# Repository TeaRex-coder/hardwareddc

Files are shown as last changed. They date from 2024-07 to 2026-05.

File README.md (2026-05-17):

<h1 align="center">HardwareDDC</h1>
<h4 align="center">A custom PCB that makes adjusting monitor settings easy and convenient</h4>

<!-- Horizontal layout with 3 images -->
<p align="center">
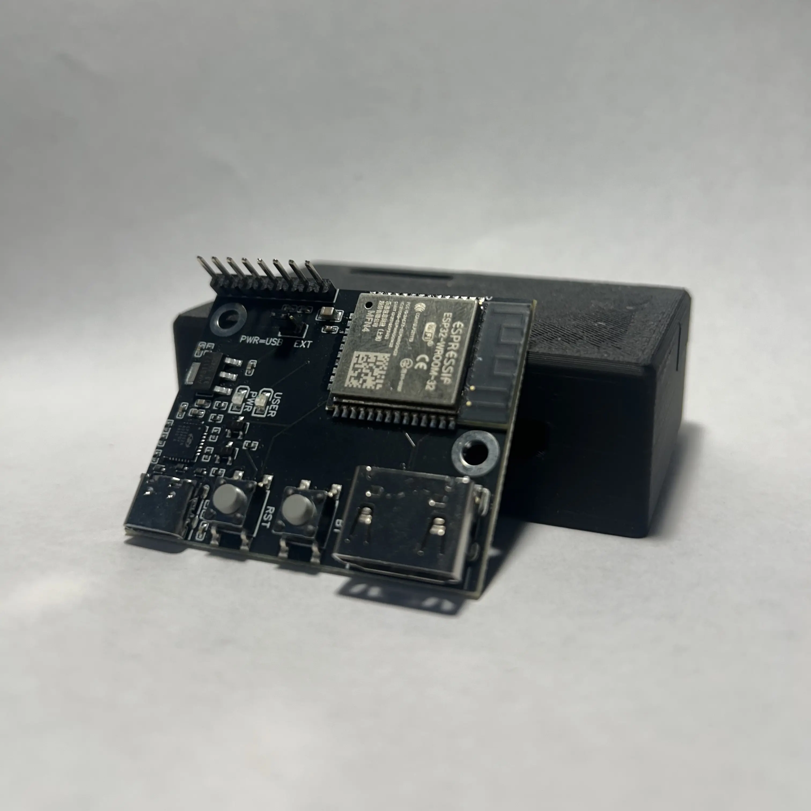
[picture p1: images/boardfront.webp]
front-view
  
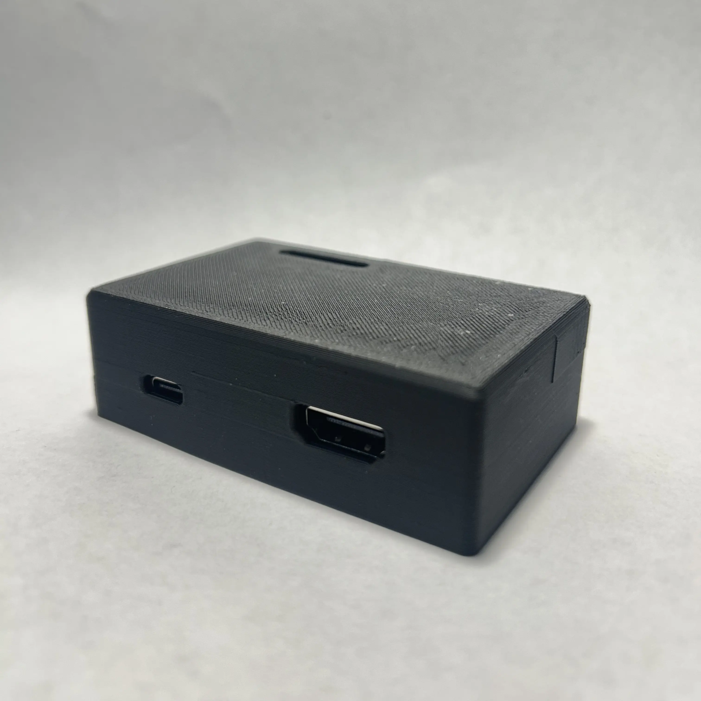
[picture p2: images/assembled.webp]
assembled
  
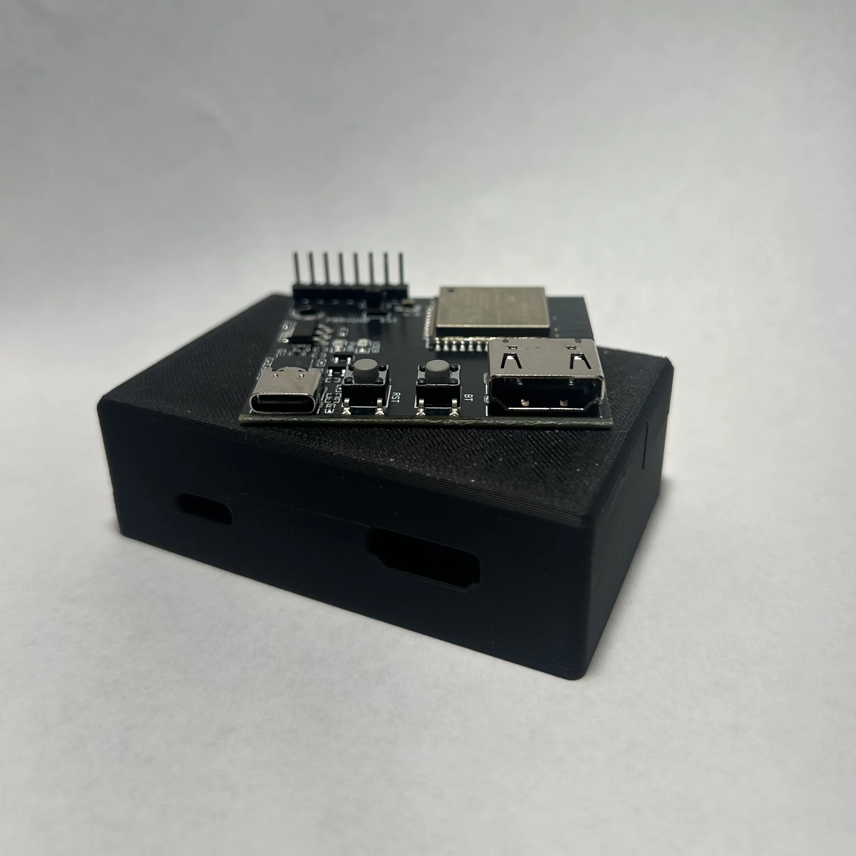
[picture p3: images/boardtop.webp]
top-view
  
</p>

## What is DDC?

DDC/CI (Display Data Channel Command Interface) lets you control monitors with software instead of navigating the nipple or rear buttons. In a perfect world, we could control all monitors with DDC, but unfortunately, that's not the case...

- Some monitors simply don't support DDC :(
- Some monitors like Samsung's G9 ultrawides support DDC only on HDMI
- \*nix (i.e. macOS & Linux) users of DisplayLink don't have DDC support
- Your monitor only supports DDC through HDMI (not DisplayPort)

If you're in one of those last three situations HardwareDDC might be for you! It uses an ESP32 to send raw I<sup>2</sup>C DDC signals to your monitor's HDMI port while another port is used for video.

## Getting Started

HardwareDDC features an ESP32 with reset and boot buttons, an HDMI connector exposing GND, SDA and SCL, and it's powered by USB-C which also exposes the UART console. Optionally, it can be powered by 5V directly through the GPIO pins, and additional GPIO pins are available for debugging and future expandability.

The PCB and the 3D printed ABS case are available on the [website](https://hardwareddc.alexandreboutoille.com), and the files can be found [here](./hardware/README.md).

Once you have your board, you can flash the firmware with the [web installer](https://hardwareddc.alexandreboutoille.com).

Controlling HardwareDDC is done through hotkeys, instructions can be found [here](./ui/README.md)

---

## Sponsors

PCBWay Logo

Thank you PCBWay for sponsoring this project providing PCB prototyping <3

<details>
<summary>Review & Opinions</summary>

TL;DR Would I recommend PCBWay's PCB service? Yes!

It's impossible for me to provide an unbiased opinion as PCBWay has provided boards free of charge to help me work on this project. However, my experience was overall positive. Starting with their marketing rep Liam, he offered a partnership respectfully and fairly. When placing the order, the team helped me, a novice to PCB design and PCBWay's services, follow some best practices regarding board design and ordering. Finally, the production tracker helped keep my curious mind informed and the assembled product functioned as intended.

When researching PCBWay's brand before agreeing to a partnership, I noticed a customer expressing disappointment in the assembly of an HDMI connector. I took this with a grain of salt, as the dissatisfied customers are generally the loudest, but it was still a concern. The boards I received had well-soldered DisplayPort connector pins to a level as good, if not better than I could do by hand.

<p align="center">
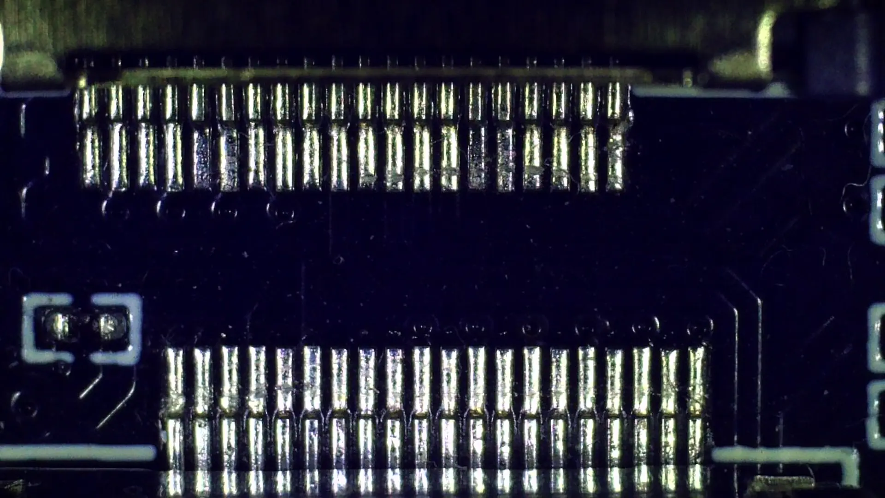
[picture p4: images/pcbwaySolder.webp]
PCBWay Logo
  
</p>

I hope the experience I received is representative of any regular PCBWay customer despite PCBWay expecting a review. If you need PCB prototyping for your project, consider giving them a go :)

</details>

Flux Logo

Thank you Flux AI for providing [breakout boards](./experiments/hardwareddc-aux-breakout) for HardwareDDC <3

## Future Ideas

- [x] Improve Microsoft Windows UX/Create Proper User Interface
  - [ ] Add more information to GUI (e.g. connection status)
  - [ ] Enable user-modifiable hotkeys
- [ ] Support Multiple Monitors
- [ ] Create a non-network-based approach

## Extras

Shoutout to these projects that make HardwareDDC possible:

- [ESP Web Tools](https://github.com/esphome/esp-web-tools)
- [Improv Wi-Fi](https://github.com/jnthas/Improv-WiFi-Library)
- [DDC/CI VCP library](https://github.com/tttttx2/ddcvcp)

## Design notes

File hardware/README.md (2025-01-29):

# Hardware

HardwareDDC comes with an optional two-part 3D-printed case which you can re-print yourself.

## BOM:

| Quantity | Description |
| --- | --- |
| 4 | M3x4x5 Heat set insert (the "Voron ones") |
| 2 | M3x6 BHCS |
| 4 | M3x6 FHCS |
| 1 | [Printed parts](./case/) |

## Print settings:

_it doesn't matter that much, but it's what I used_

- Layer height: 0.2mm
- Extrusion width: 0.4mm
- Infill: 20%
- Walls: 4
- Top/bottom layers: 5
- No supports
- Material: Board gets warm so I used ABS, but PLA should work

## Assembly:

### Step 1: Add Heatset Inserts

- 4 x Heat Set Insert

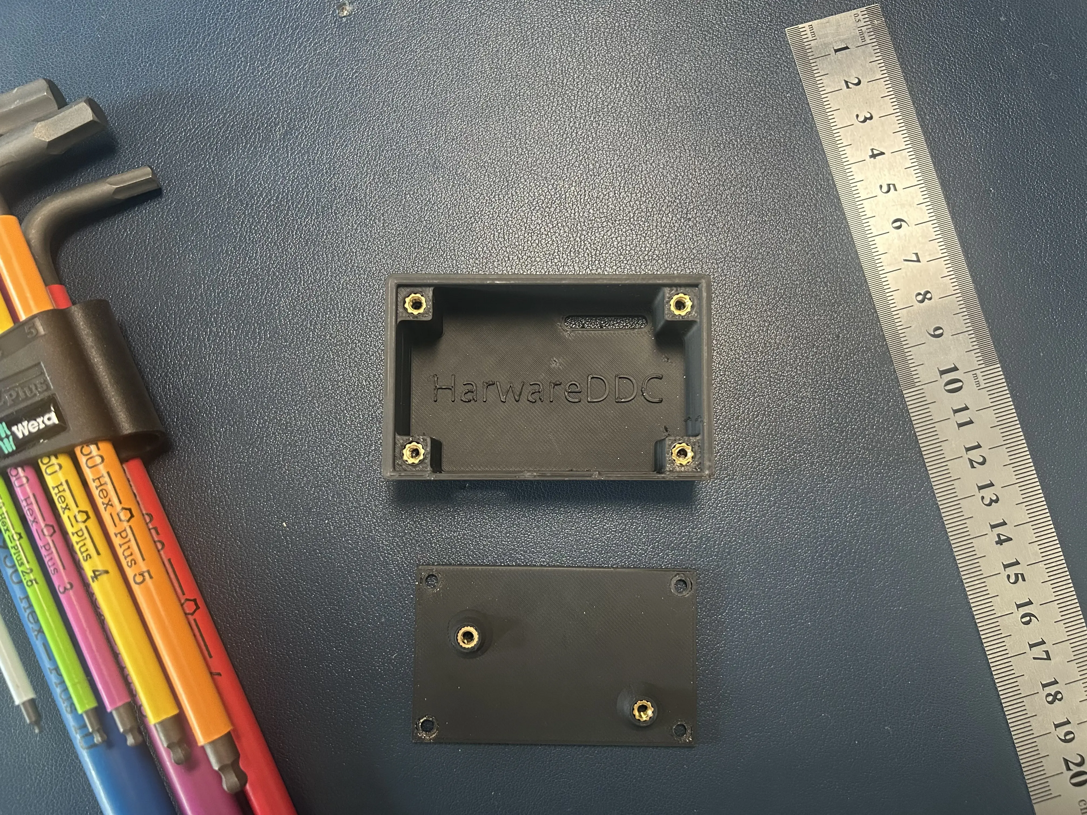
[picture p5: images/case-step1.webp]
case step 1


<br>

### Step 2: Place PCB

- 2 x M3x6 BHCS

_Make sure fasteners are centered in the board holes (future revision will reduce the tolerance)_

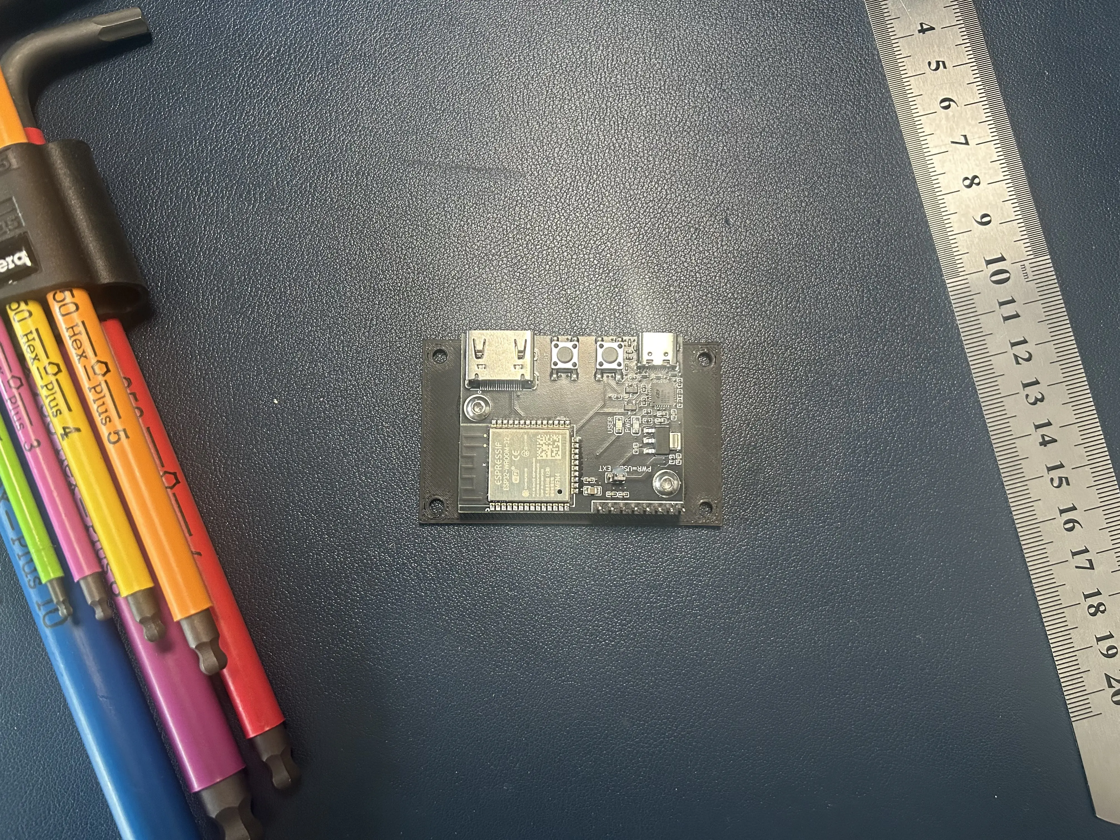
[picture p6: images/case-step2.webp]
case step 2


<br>

### Step 3: Close Case

- 4 x M3x6 FHCS

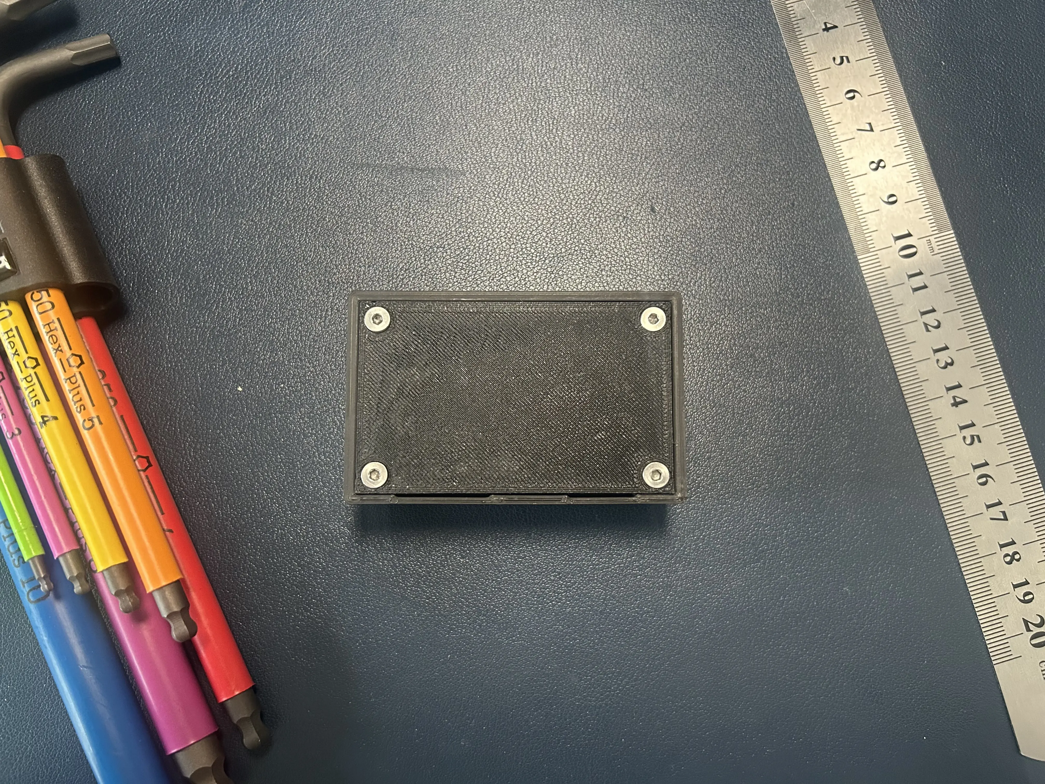
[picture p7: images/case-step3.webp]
case step 3


<br>

_The PCB is not yet fully open-source, however the schematic can be found [here](./pcb/HardwareDDC_rev1.0_schematic.pdf.pdf)_

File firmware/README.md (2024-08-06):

# Firmware

## Building

HardwareDDC is built using Espressif's ESP32-WROOM-32E-N4.

Build environment tools:

- [esptool.py](https://github.com/espressif/esptool)
- [PlatformIO](https://github.com/platformio)

### Generate image

```bash
esptool.py --chip esp32 merge_bin -o image.bin --flash_mode dio --flash_size 4MB 0x1000 .pio/build/esp32dev/bootloader.bin 0x8000 .pio/build/esp32dev/partitions.bin 0x10000 .pio/build/esp32dev/firmware.bin
```

### Flash Image

```bash
esptool.py --chip esp32 --port <serial port> write_flash 0x0 image.bin
```

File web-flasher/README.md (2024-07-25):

# Web Installer

HardwareDDC's web installer uses [ESP Web Tools](https://github.com/esphome/esp-web-tools) to connects to the ESP32's UART console with [esptool-js](https://github.com/espressif/esptool-js) and uses [Improv](https://github.com/improv-wifi) to configure Wi-Fi over serial.

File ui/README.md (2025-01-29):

# User Interface

HardwareDDC's goal is to provide and easy and convenient way to adjust monitor settings. Currently, HardwareDDC is controlled through an efficient macro-based UI.

## macOS

Lunar, _the defacto app for controlling monitors_, is used as HardwareDDC's macOS GUI.

1. Install [Lunar](https://static.lunar.fyi/releases/Lunar.dmg)
2. Disable all controls aside from _Network (Raspberry Pi)_
3. Reset _Network Control_

## Windows

1. Install [hardwareddc-amd64-installer.exe](https://github.com/TeaRex-coder/hardwareddc/releases) from the latest GitHub release

### Hotkeys

_User-modifiable hotkeys to come_

**Brightness:**

- ⌥⇧- = +10%
- ⌥⇧= = +10%

- ⌥⇧1 = 25%
- ⌥⇧2 = 50%
- ⌥⇧3 = 75%
- ⌥⇧4 = 100%
- ⌥⇧5 = 0%

**Input Source:**

- ⌥⇧d1 = DisplayPort 1
- ⌥⇧d2 = DisplayPort 2
- ⌥⇧h1 = HDMI 1
- ⌥⇧h2 = HDMI 2

## Linux

_Sorry, GNU/Linux_

This is coming soon, but you're a Linux user, you can figure it out.

**Example API calls to get you started:**

Specify brightness percentage:

```bash
curl -X GET "http://ddcutil.local:3485/1/brightness/<value 0-100>"
```

Get current brightness:

```bash
curl -X GET "http://ddcutil.local:3485/1/brightness"
```

Change input source:

```bash
curl -X GET "http://ddcutil.local:3485/1/input_source/<hexadecimal source>"
```

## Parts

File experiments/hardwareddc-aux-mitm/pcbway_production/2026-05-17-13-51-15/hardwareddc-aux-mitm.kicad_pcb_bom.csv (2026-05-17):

Designator | Quantity | Value | Footprint | Package | MPN | DNP | Mount_Type | Description | KiLib_Generator | MF | MP | Description_1 | Price
C1, C3, C4, C5, C8, C9 | 6 | 100n | C_0402_1005Metric |  |  |  | smt | Unpolarized capacitor | SMD_2terminal_chip_molded
C10, C7 | 2 | 10uF | C_0603_1608Metric |  |  |  | smt | Unpolarized capacitor | SMD_2terminal_chip_molded
C11 | 1 | 100nF | C_0603_1608Metric |  |  |  | smt | Unpolarized capacitor | SMD_2terminal_chip_molded
C2, C6 | 2 | 1n | C_0402_1005Metric |  |  |  | smt | Unpolarized capacitor | SMD_2terminal_chip_molded
D1 | 1 | D_TVS | D_SOD-323 |  |  |  | smt | Bidirectional transient-voltage-suppression diode
J1, J4 | 2 | 47272-0001 | CONN_47272-0001_MOL |  |  |  | smt |  |  | Molex | 472720001
J5 | 1 | HDMI_A | HDMI_A_Molex_208658-1001_Horizontal |  |  |  | smt | HDMI type A connector
J6 | 1 | USB_C_Receptacle_USB2.0_16P | USB_C_Receptacle_GCT_USB4105-xx-A_16P_TopMnt_Horizontal |  |  |  | smt | USB 2.0-only 16P Type-C Receptacle connector
J7 | 1 | Conn_02x02_Odd_Even | PinHeader_2x02_P2.54mm_Vertical |  |  |  | tht | Generic connector, double row, 02x02, odd/even pin numbering scheme (row 1 odd numbers, row 2 even numbers), script generated (kicad-library-utils/schlib/autogen/connector/) | connector/pin_header_socket
J8 | 1 | Conn_02x04_Odd_Even | PinHeader_2x04_P2.54mm_Vertical |  |  |  | tht | Generic connector, double row, 02x04, odd/even pin numbering scheme (row 1 odd numbers, row 2 even numbers), script generated (kicad-library-utils/schlib/autogen/connector/) | connector/pin_header_socket
R1, R8 | 2 | 10k | R_0402_1005Metric |  |  |  | smt | Resistor | SMD_2terminal_chip_molded
R10, R3 | 2 | 1K5 | R_0402_1005Metric |  |  |  | smt | Resistor | SMD_2terminal_chip_molded
R11, R12, R4, R5 | 4 | 51 | R_0402_1005Metric |  |  |  | smt | Resistor | SMD_2terminal_chip_molded
R13, R14 | 2 | 1M | R_0402_1005Metric |  |  |  | smt | Resistor | SMD_2terminal_chip_molded
R15, R16, R17, R18, R19, R20 | 6 | 0 | R_0603_1608Metric |  |  |  | smt | Resistor | SMD_2terminal_chip_molded
R2, R9 | 2 | 3K3 | R_0402_1005Metric |  |  |  | smt | Resistor | SMD_2terminal_chip_molded
R21, R22 | 2 | 5K1 | R_0402_1005Metric |  |  |  | smt | Resistor | SMD_2terminal_chip_molded
R6, R7 | 2 | 100K | R_0402_1005Metric |  |  |  | smt | Resistor | SMD_2terminal_chip_molded
U1, U2 | 2 | SN65MLVD200AD | SOIC-8_3.9x4.9mm_P1.27mm | SOIC-8 Texas Instruments |  |  | smt |  | package/gullwing | Texas Instruments | SN65MLVD200AD | Half-duplex M-LVDS transceiver | None
U3 | 1 | AMS1117-3.3 | SOT-223-3_TabPin2 |  |  |  | smt | 1A Low Dropout regulator, positive, 3.3V fixed output, SOT-223

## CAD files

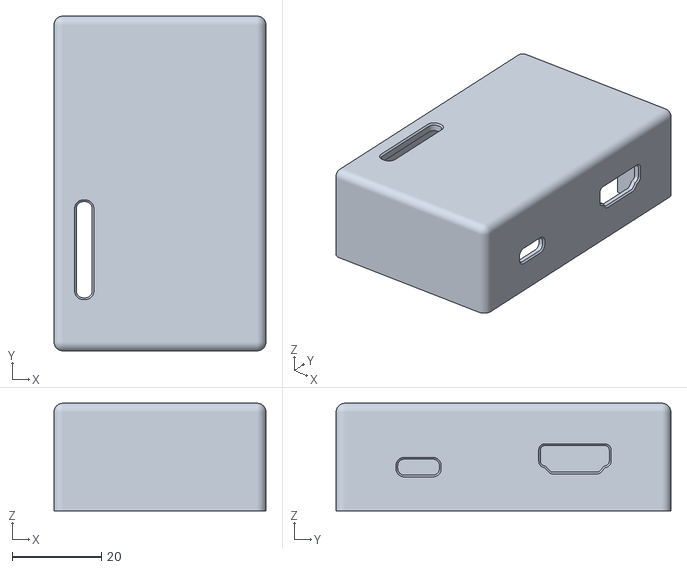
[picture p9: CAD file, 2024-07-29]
hardware/case/HardwareDDC-case-top.stl
47.5 x 75.0 x 24.1

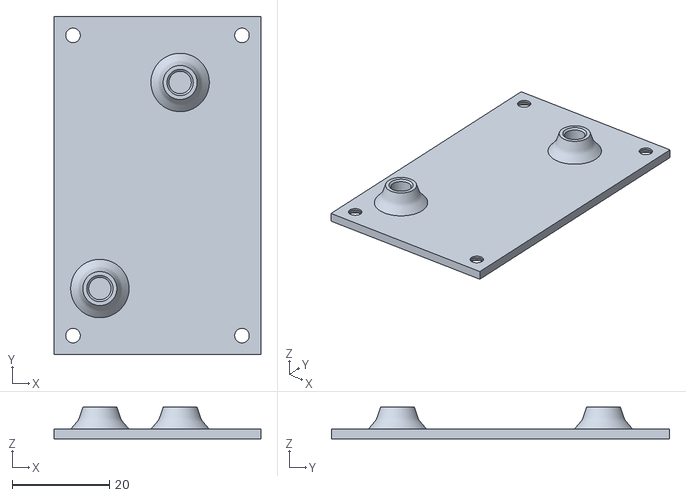
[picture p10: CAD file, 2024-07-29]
hardware/case/HardwareDDC-case-bottom.stl
42.5 x 69.5 x 6.50

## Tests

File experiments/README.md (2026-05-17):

# HardwareDDC Experiments

_I do a lot of work behind the scene to learn about DDC-related tech. In this directory, I want to share some of my fun HardwareDDC experiments._

## HardwareDDC Aux V1.0

This board uses the [PTN3392](https://www.nxp.com/docs/en/data-sheet/PTN3392.pdf) DisplayPort to VGA IC to convert DP Aux into i2c

Goals:

- Reduce latency
- No client software

[Schematic](./hardwareddc-aux-v1.0/hardwareddc-aux-v1.0.pdf)

[ECAD files](./hardwareddc-aux-v1.0/hardwareddc-aux-v1.0.zip)

Learnings:

- This solution is jank and pretty unstable
- Next time, I'll try using [TI's M-LVDS](https://www.ti.com/lit/ug/tidu599/tidu599.pdf) transceivers to interact with the Aux channel

## HardwareDDC Aux 2.0 "Breakout"

This board _attempts_ to "sniff" the DisplayPort auxiliary channel using [TI's SN65MLVD200AD](https://www.ti.com/lit/ds/symlink/sn65mlvd200a.pdf).

What I learned:

- How to better route high-speed differential pairs (DisplayPort video signal)
- Improved understanding of DisplayPort AUX

What didn't work:

- Sniffing the AUX channel

I think it didn't work because of my false assumptions of the physical hardware layout of DisplayPort AUX on both the source and sink. Possible also because of the assumptions I made before understanding the communication protocol.

In the future, I'll be trying using a more traditional Hardware layout as suggested in the DisplayPort 1.2 standards document to using a more MitM-like approach inspired by [JX5S' work](https://github.com/JX5S/DP_aux_emulator).

## HardwareDDC AUX 2.1 "MitM"

WIP

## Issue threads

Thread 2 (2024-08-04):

Incorrect values for input sources for Odyssey G9 OLED

dlpullen, 2024-08-04:
Currently, the code limits the "valid" input source values to 4 values in the handleSetSource function in http.cpp.

These values are:
- 0x0f
- 0x10
- 0x11
- 0x12

The Odyssey G9 OLED is apparently a little different. It only has 3 inputs and the values are:
- 0x05 (Full-size HDMI aka HDMI 1)
- 0x06 (Mini HDMI aka HDMI 2)
- 0x0f (Display Port)

I would propose to either remove the check in line 108 in http.cpp or to add these values to the checked items. I am unsure how much variety there is across different monitors that might benefit from hardwareddc.

As a quick point of comparison, I have some Dell 2721QS monitors with fantastic ddc support. So, no need for hardwareddc for them. But, There input values are:
- 0x0f (Display Port)
- 0x11 (HDMI 1)
- 0x12 (HDMI 2)

These are in better alignment (a subset) with the values you already have setup in the if statement.

TeaRex-coder, 2024-08-06:
Thanks for opening your issue! I've re-written the API endpoints and removed the check in `http.cpp`.

To switch to HDMI 1 you can now send a request to `http://ddcutil.local:3485/1/input_source/0x05`, more info in the [documentation](/TeaRex-coder/hardwareddc/tree/main/ui).

I'll merge the `api-v2` branch with a PR and close this issue.

Closed 2024-08-06.

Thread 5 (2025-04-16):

ESP32 with HDMI port

denisgabriel5, 2025-04-16:
My question is where can I purchase and ESP32 with an HDMI port.

I did a quick Google search and I couldn't find such a device.

If it is possible, I would appreciate a link to such a device that is available to purchase from within the European Union.

TeaRex-coder, 2025-06-28:
Answered on [Reddit](https://old.reddit.com/r/ultrawidemasterrace/comments/1dxoh3b/comment/mne3k59/)

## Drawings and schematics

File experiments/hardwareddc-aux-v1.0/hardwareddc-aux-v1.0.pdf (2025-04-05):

# HardwareDDC Aux

DP INPUT | DP OUTPUT | HDMI OUTPUT

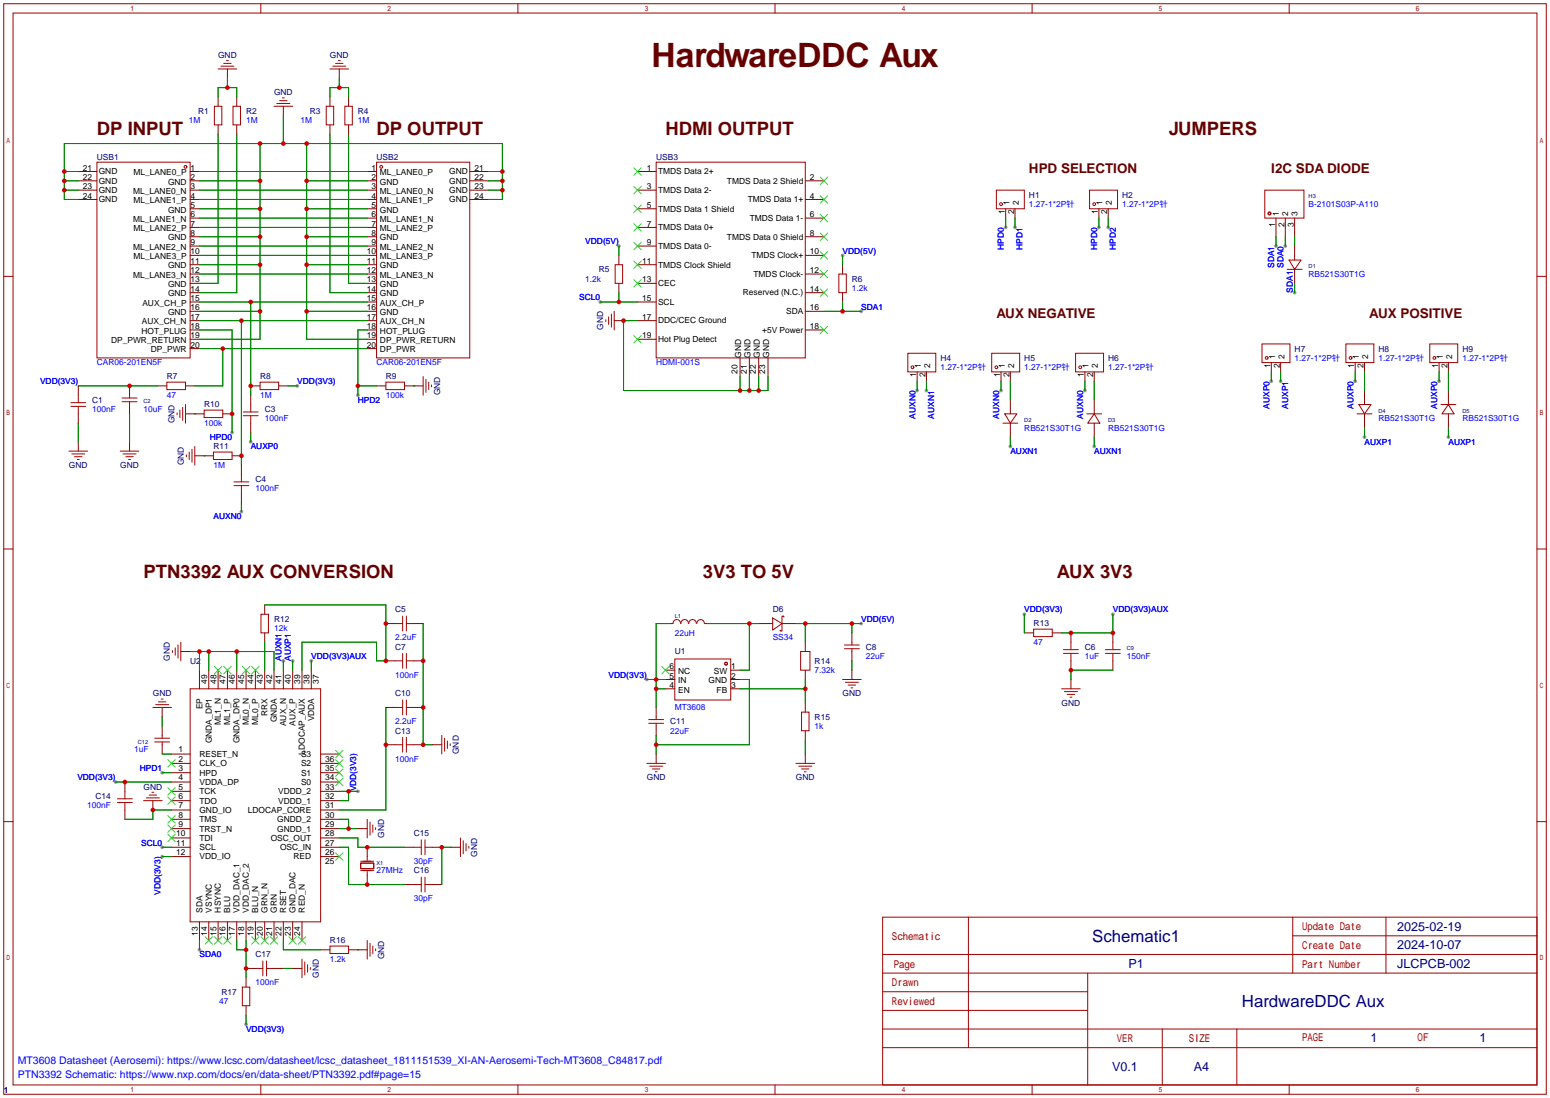
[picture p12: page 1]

EP 49 GNDA_DP1 48 ML1_N 47 ML1_P 46 GNDA_DP0 45 ML0_N 44 ML0_P 43 RRX 42 GNDA 41 AUX_N 40 AUX_P 39 LDOCAP_AUX 38 VDDA 37

MT3608 Datasheet (Aerosemi): https://www.lcsc.com/datasheet/lcsc_datasheet_1811151539_XI-AN-Aerosemi-Tech-MT3608_C84817.pdf
PTN3392 Schematic: https://www.nxp.com/docs/en/data-sheet/PTN3392.pdf#page=15

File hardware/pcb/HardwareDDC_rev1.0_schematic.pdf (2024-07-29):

# HardwareDDC

POWER INPUT SELECTION | 5V TO 3.3V | POWER LED | USER LED

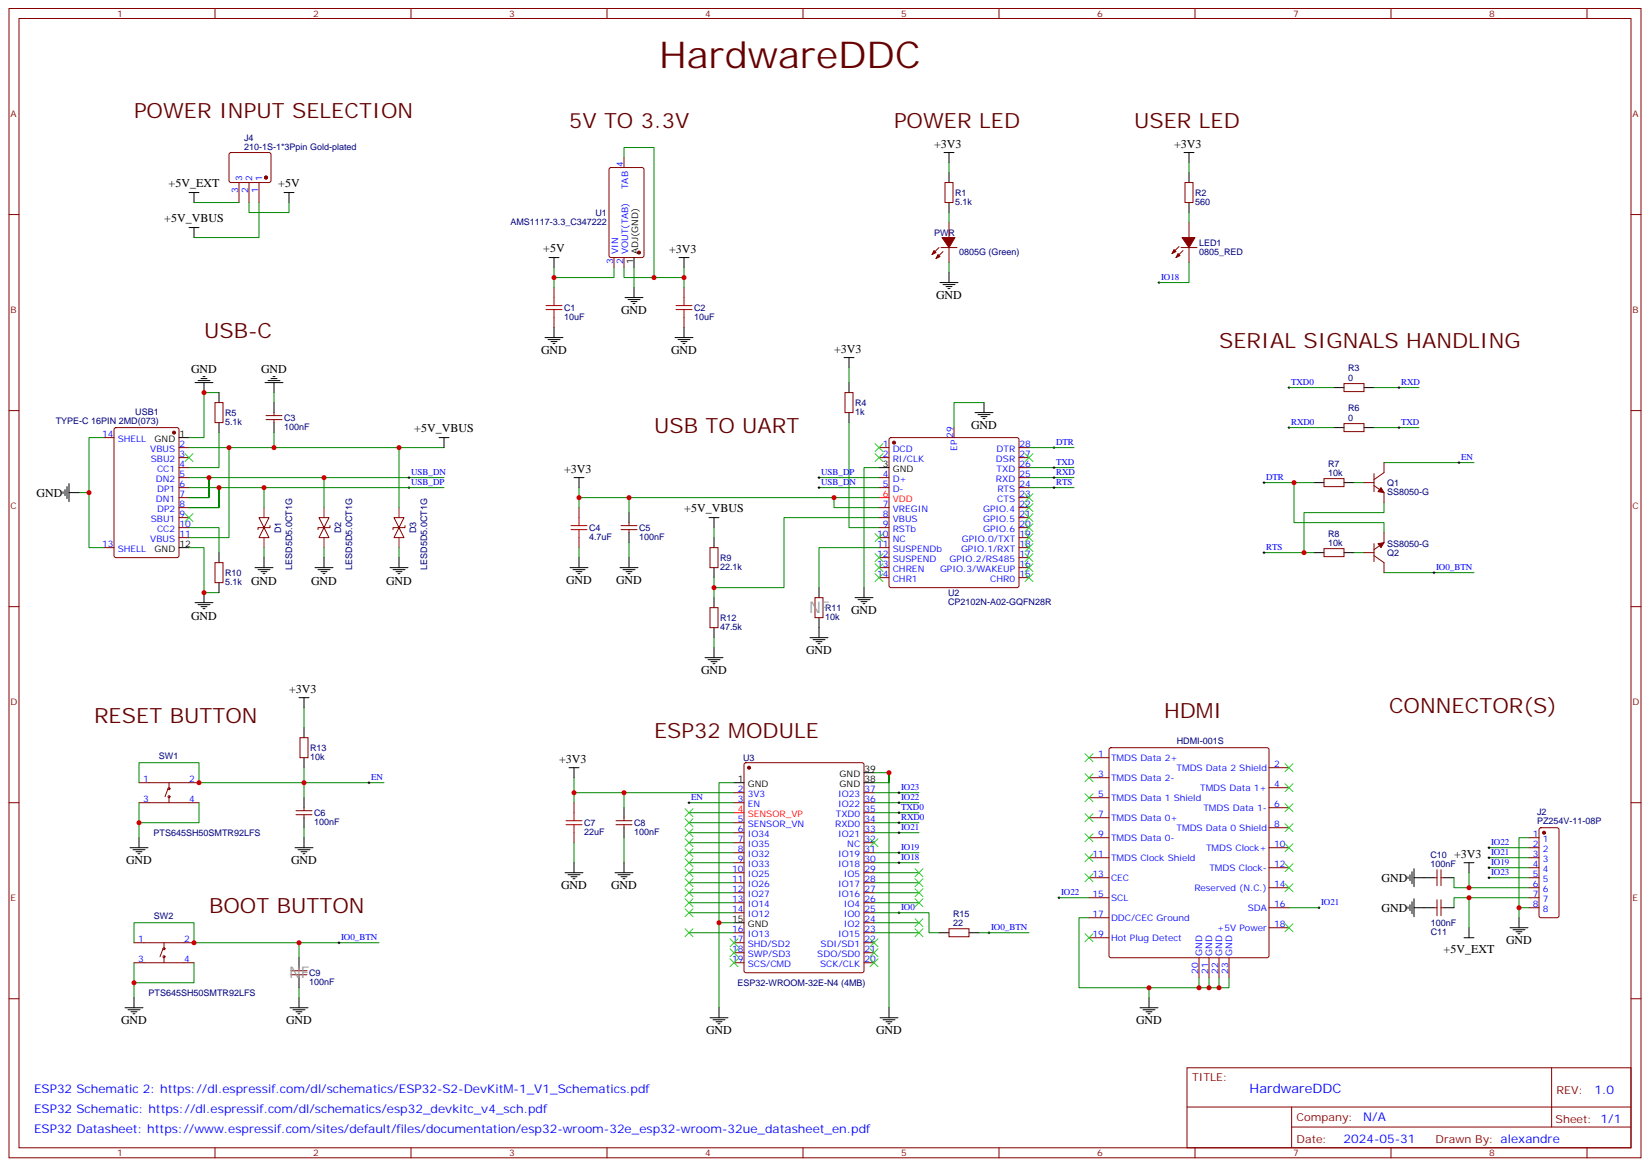
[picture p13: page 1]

ESP32 Schematic 2: https://dl.espressif.com/dl/schematics/ESP32-S2-DevKitM-1_V1_Schematics.pdf
ESP32 Schematic: https://dl.espressif.com/dl/schematics/esp32_devkitc_v4_sch.pdf
ESP32 Datasheet: https://www.espressif.com/sites/default/files/documentation/esp32-wroom-32e_esp32-wroom-32ue_datasheet_en.pdf

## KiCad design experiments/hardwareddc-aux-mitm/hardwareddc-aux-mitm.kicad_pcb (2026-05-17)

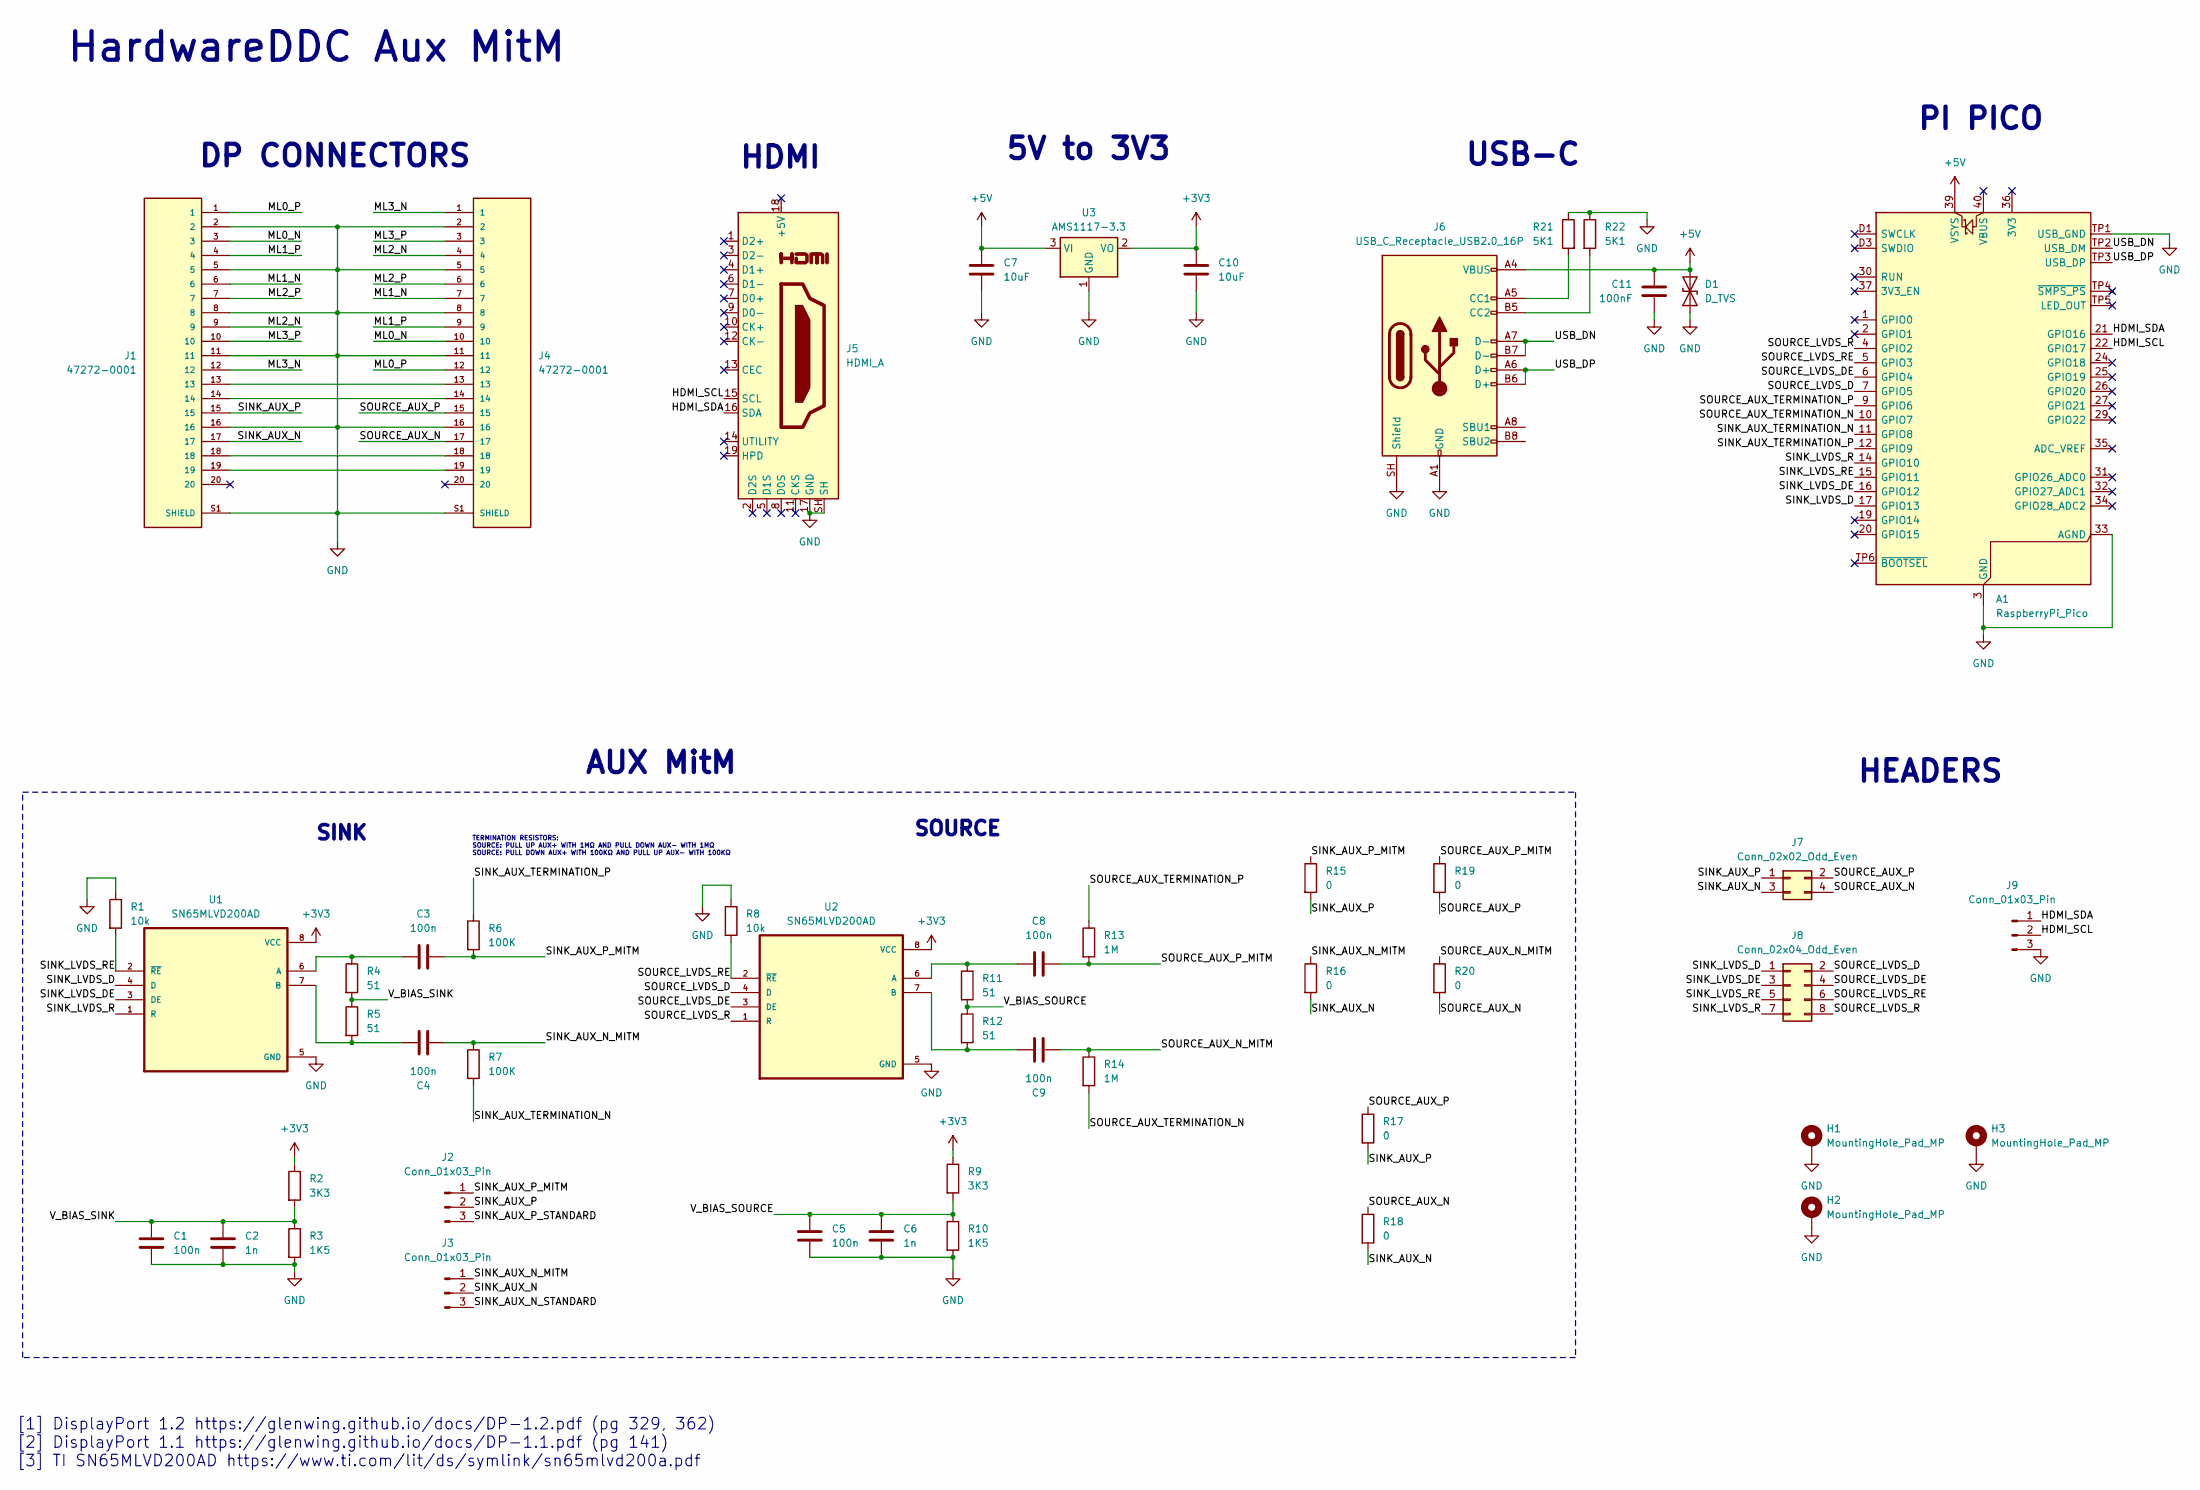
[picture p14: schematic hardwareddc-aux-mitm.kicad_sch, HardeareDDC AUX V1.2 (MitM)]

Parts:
A1: RaspberryPi_Pico; RaspberryPi_Pico_SMD
C1, C3, C4, C5, C8, C9: 100n; C_0402_1005Metric
C2, C6: 1n; C_0402_1005Metric
C7, C10: 10uF; C_0603_1608Metric
C11: 100nF; C_0603_1608Metric
D1: D_TVS; D_SOD-323
H1, H2, H3: MountingHole_Pad_MP; MountingHole_2.2mm_M2_ISO7380_Pad
J1, J4: 47272-0001; CONN_47272-0001_MOL
J2, J3: Conn_01x03_Pin
J5: HDMI_A; HDMI_A_Molex_208658-1001_Horizontal
J6: USB_C_Receptacle_USB2.0_16P; USB_C_Receptacle_GCT_USB4105-xx-A_16P_TopMnt_Horizontal
J7: Conn_02x02_Odd_Even; PinHeader_2x02_P2.54mm_Vertical
J8: Conn_02x04_Odd_Even; PinHeader_2x04_P2.54mm_Vertical
J9: Conn_01x03_Pin; PinHeader_1x03_P2.54mm_Vertical
R1, R8: 10k; R_0402_1005Metric
R2, R9: 3K3; R_0402_1005Metric
R3, R10: 1K5; R_0402_1005Metric
R4, R5, R11, R12: 51; R_0402_1005Metric
R6, R7: 100K; R_0402_1005Metric
R13, R14: 1M; R_0402_1005Metric
R15, R16, R17, R18, R19, R20: 0; R_0603_1608Metric
R21, R22: 5K1; R_0402_1005Metric
U1, U2: SN65MLVD200AD; SOIC-8_3.9x4.9mm_P1.27mm
U3: AMS1117-3.3; SOT-223-3_TabPin2

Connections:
+3V3: C10.1, R2.1, R9.1, U1.8 (VCC), U2.8 (VCC), U3.2 (VO)
+5V: A1.39 (VSYS), C7.1, C11.1, D1.2 (A2), J6.A4 (VBUS), J6.A9 (VBUS), J6.B4 (VBUS), J6.B9 (VBUS), U3.3 (VI)
/HDMI_SCL: A1.22 (GPIO17), J5.15 (SCL), J9.2
/HDMI_SDA: A1.21 (GPIO16), J5.16 (SDA), J9.1
/ML0_N: J1.3, J4.10
/ML0_P: J1.1, J4.12
/ML1_N: J1.6, J4.7
/ML1_P: J1.4, J4.9
/ML2_N: J1.9, J4.4
/ML2_P: J1.7, J4.6
/ML3_N: J1.12, J4.1
/ML3_P: J1.10, J4.3
/SINK_AUX_N: J1.17, J3.2, J7.3, R16.2, R18.2
/SINK_AUX_N_MITM: C4.2, J3.1, R7.1, R16.1
/SINK_AUX_P: J1.15, J2.2, J7.1, R15.2, R17.2
/SINK_AUX_P_MITM: C3.2, J2.1, R6.2, R15.1
/SINK_AUX_TERMINATION_N: A1.11 (GPIO8), R7.2
/SINK_AUX_TERMINATION_P: A1.12 (GPIO9), R6.1
/SINK_LVDS_D: A1.17 (GPIO13), J8.1, U1.4 (D)
/SINK_LVDS_DE: A1.16 (GPIO12), J8.3, U1.3 (DE)
/SINK_LVDS_R: A1.14 (GPIO10), J8.7, U1.1 (R)
/SINK_LVDS_RE: A1.15 (GPIO11), J8.5, R1.2, U1.2 (~RE)
/SOURCE_AUX_N: J4.17, J7.4, R18.1, R20.2
/SOURCE_AUX_N_MITM: C9.2, R14.1, R20.1
/SOURCE_AUX_P: J4.15, J7.2, R17.1, R19.2
/SOURCE_AUX_P_MITM: C8.2, R13.2, R19.1
/SOURCE_AUX_TERMINATION_N: A1.10 (GPIO7), R14.2
/SOURCE_AUX_TERMINATION_P: A1.9 (GPIO6), R13.1
/SOURCE_LVDS_D: A1.7 (GPIO5), J8.2, U2.4 (D)
/SOURCE_LVDS_DE: A1.6 (GPIO4), J8.4, U2.3 (DE)
/SOURCE_LVDS_R: A1.4 (GPIO2), J8.8, U2.1 (R)
/SOURCE_LVDS_RE: A1.5 (GPIO3), J8.6, R8.2, U2.2 (~RE)
/USB_DN: A1.TP2 (USB_DM), J6.A7 (D-), J6.B7 (D-)
/USB_DP: A1.TP3 (USB_DP), J6.A6 (D+), J6.B6 (D+)
/V_BIAS_SINK: C1.1, C2.1, R2.2, R3.1, R4.2, R5.1
/V_BIAS_SOURCE: C5.1, C6.1, R9.2, R10.1, R11.2, R12.1
GND: A1.3 (GND), A1.8 (GND), A1.13 (GND), A1.18 (GND), A1.23 (GND), A1.28 (GND), A1.33 (AGND), A1.38 (GND), A1.D2 (GND), A1.TP1 (USB_GND), C1.2, C2.2, C5.2, C6.2, C7.2, C10.2, C11.2, D1.1 (A1), H1.1 (MP_1), H2.1 (MP_1), H3.1 (MP_1), J1.2, J1.5, J1.8, J1.11, J1.16, J1.S1 (SHIELD), J1.S2 (SHIELD), J1.S3 (SHIELD), J1.S4 (SHIELD), J4.2, J4.5, J4.8, J4.11, J4.16, J4.S1 (SHIELD), J4.S2 (SHIELD), J4.S3 (SHIELD), J4.S4 (SHIELD), J5.17 (GND), J5.SH, J6.A1 (GND), J6.A12 (GND), J6.B1 (GND), J6.B12 (GND), J6.SH (Shield), J9.3, R1.1, R3.2, R8.1, R10.2, R21.1, R22.1, U1.5 (GND), U2.5 (GND), U3.1 (GND)
unnamed: J1.13, J4.13
unnamed: J1.14, J4.14
unnamed: J1.18, J4.18
unnamed: J1.19, J4.19
unnamed: J6.A5 (CC1), R21.2
unnamed: J6.B5 (CC2), R22.2
unnamed: C3.1, R4.1, U1.6 (A)
unnamed: C4.1, R5.2, U1.7 (B)
unnamed: C8.1, R11.1, U2.6 (A)
unnamed: C9.1, R12.2, U2.7 (B)

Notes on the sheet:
SOURCE
DP CONNECTORS
HardwareDDC Aux MitM
[1] DisplayPort 1.2 https://glenwing.github.io/docs/DP-1.2.pdf (pg 329, 362) [2] DisplayPort 1.1 https://glenwing.github.io/docs/DP-1.1.pdf (pg 141) [3] TI SN65MLVD200AD https://www.ti.com/lit/ds/symlink/sn65mlvd200a.pdf
HEADERS
AUX MitM
5V to 3V3
USB-C
PI PICO
SINK
TERMINATION RESISTORS: SOURCE: PULL UP AUX+ WITH 1MΩ AND PULL DOWN AUX- WITH 1MΩ SOURCE: PULL DOWN AUX+ WITH 100KΩ AND PULL UP AUX- WITH 100KΩ
HDMI

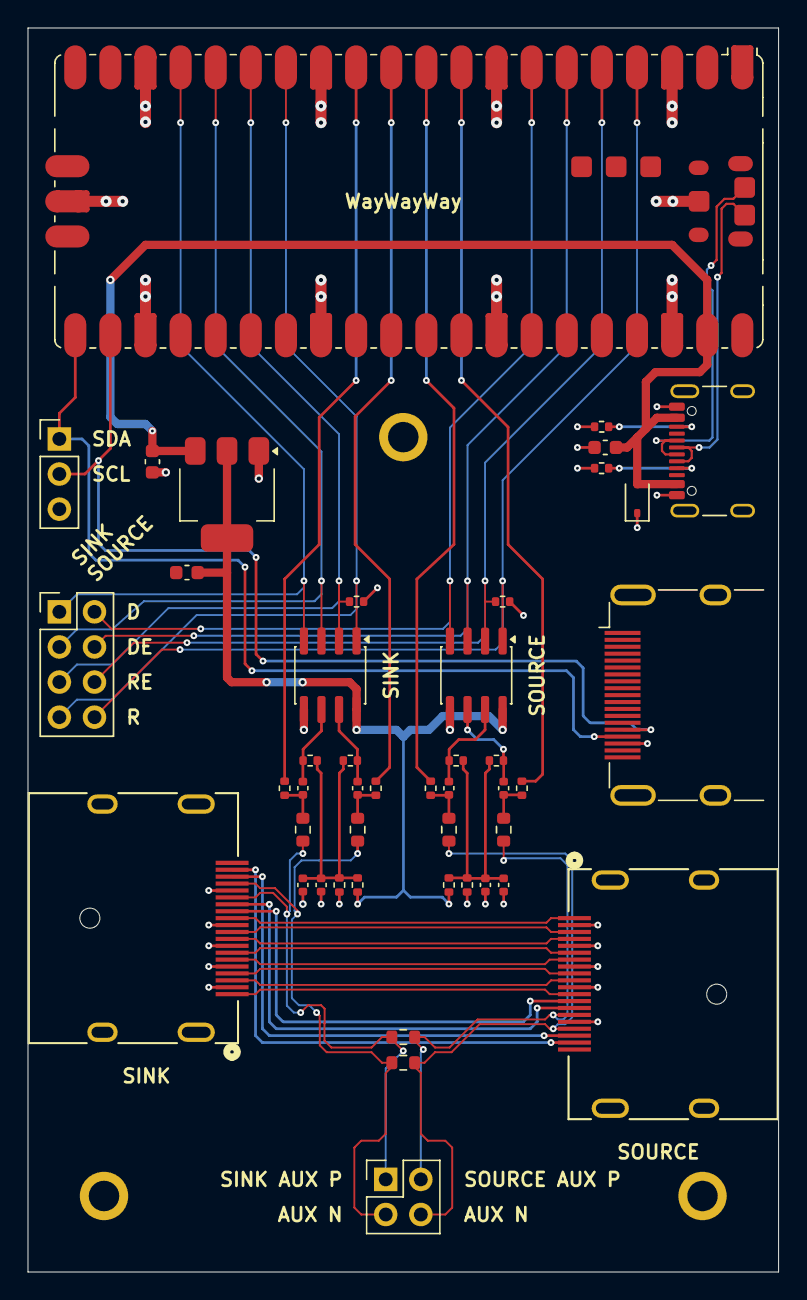
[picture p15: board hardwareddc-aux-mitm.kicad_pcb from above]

Board: 4 copper layers, 54.3 x 90.0 mm, 48 parts (0 on the bottom side), 47 nets.

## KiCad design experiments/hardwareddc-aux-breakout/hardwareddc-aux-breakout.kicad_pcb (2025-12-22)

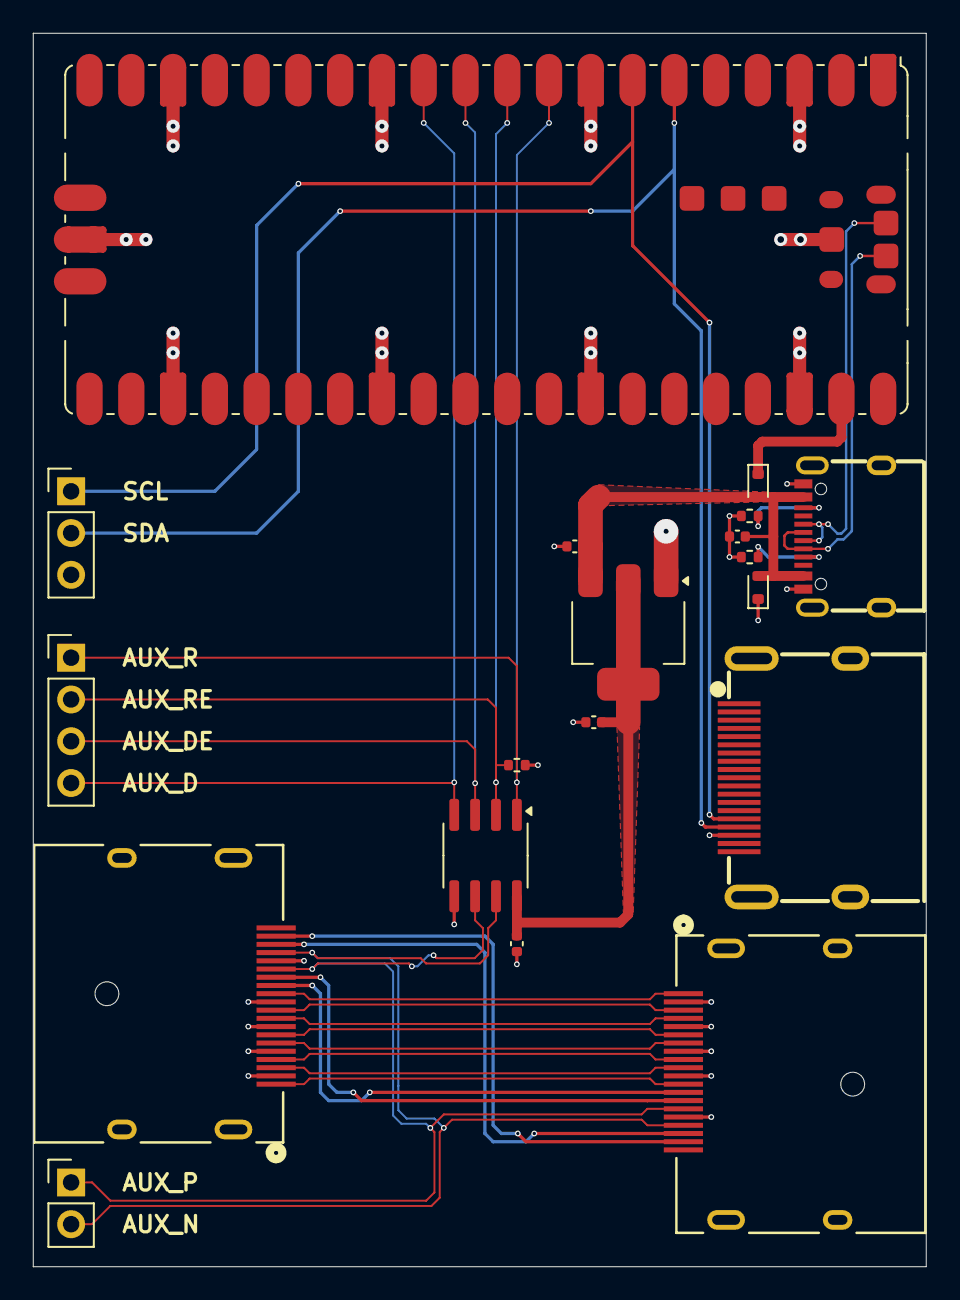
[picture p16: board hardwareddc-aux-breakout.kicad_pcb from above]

Board: 4 copper layers, 54.3 x 75.0 mm, 19 parts (0 on the bottom side), 28 nets.

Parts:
A1: RaspberryPi_Pico; RaspberryPi_Pico_SMD
C1, C2: 100nF; C_0402_1005Metric
C3, C4: 10uF; C_0402_1005Metric
D1: D_TVS; D_SOD-523
D2: D_Schottky; D_SOD-523
J1: Conn_01x04_Pin; PinHeader_1x04_P2.54mm_Vertical
J2: USB_C_Receptacle; USB-C-SMD_TYPE-C-6PIN-2MD-073
J3: Conn_01x03_Pin; PinHeader_1x03_P2.54mm_Vertical
J4: Conn_01x02_Pin; PinHeader_1x02_P2.54mm_Vertical
J5, J6: 472720001; CONN_47272-0001_MOL
J7: HDMI_A_1.4; HDMI-SMD_HDMI-19PIN-043
R1, R2: 5.1K; R_0402_1005Metric
R3: 10K; R_0402_1005Metric
U1: SN65MLVD200ADR; SOIC-8_3.9x4.9mm_P1.27mm
U2: AMS1117-3.3; SOT-223-3_TabPin2

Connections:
+3V3: C2.1, C4.1, U1.8 (VCC), U2.2 (VO)
+5V: C1.1, C3.1, D1.2 (A2), D2.2 (A), J2.A4 (VBUS), U2.3 (VI)
/AUX_D: A1.12 (GPIO9), J1.4, U1.4 (D)
/AUX_DE: A1.11 (GPIO8), J1.3, U1.3 (DE)
/AUX_N: J4.2, J5.17, J6.17, U1.7 (B)
/AUX_P: J4.1, J5.15, J6.15, U1.6 (A)
/AUX_R: A1.9 (GPIO6), J1.1, U1.1 (R)
/AUX_RE: A1.10 (GPIO7), J1.2, R3.1, U1.2 (~RE)
/ML0_N: J5.3, J6.10
/ML0_P: J5.1, J6.12
/ML1_N: J5.6, J6.7
/ML1_P: J5.4, J6.9
/ML2_N: J5.9, J6.4
/ML2_P: J5.7, J6.6
/ML3_N: J5.12, J6.1
/ML3_P: J5.10, J6.3
/SCL: A1.7 (GPIO5), J3.1, J7.15 (SCL)
/SDA: A1.6 (GPIO4), J3.2, J7.16 (SDA)
/USB_DN: A1.TP2 (USB_DM), J2.A7 (D-), J2.B7 (D-)
/USB_DP: A1.TP3 (USB_DP), J2.A6 (D+), J2.B6 (D+)
GND: A1.3 (GND), A1.8 (GND), A1.13 (GND), A1.18 (GND), A1.23 (GND), A1.28 (GND), A1.33 (AGND), A1.38 (GND), A1.D2 (GND), A1.TP1 (USB_GND), C1.2, C2.2, C3.2, C4.2, D1.1 (A1), J2.A1 (GND), J2.S1 (SHIELD), J3.3, J5.2, J5.5, J5.8, J5.11, J5.16, J5.21, J5.22, J5.23, J5.24, J6.2, J6.5, J6.8, J6.11, J6.16, J6.21, J6.22, J6.23, J6.24, J7.17 (GND), J7.SH, R1.1, R2.1, R3.2, U1.5 (GND), U2.1 (GND)
unnamed: A1.39 (VSYS), D2.1 (K)
unnamed: J2.A5 (CC1), R1.2
unnamed: J2.B5 (CC2), R2.2
unnamed: J5.13, J6.13
unnamed: J5.14, J6.14
unnamed: J5.18, J6.18
unnamed: J5.19, J6.19

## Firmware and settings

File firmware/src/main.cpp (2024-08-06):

#include <ESPmDNS.h>
#include "../include/http.h"
#include "../include/improv.h"
#include "../lib/ddc/ddc.h"

DDC ddc;
bool ddcConnected = false;

void ddcSetup() {
    Serial.begin(115200);
    while (!ddc.begin()) {
        Serial.print(F("DDC didn't connect, wait 5 sec\n"));
        delay(5000);
    }
    Serial.print(F("DDC found\n"));
    ddcConnected = true;

    String mfg = ddc.getMfg();
    String model = ddc.getModel();
    String product = ddc.getProduct();
    String serial = ddc.getSerial();
    uint32_t serialDecimal = ddc.getSerialDecimal();
    String year = String(ddc.getYear());

    MDNS.addServiceTxt("_ddcutil", "_tcp", "1:year", year.c_str());
    MDNS.addServiceTxt("_ddcutil", "_tcp", "1:serial", String(serialDecimal).c_str());
    MDNS.addServiceTxt("_ddcutil", "_tcp", "1:product", product.c_str());
    MDNS.addServiceTxt("_ddcutil", "_tcp", "1:model", model.c_str());
    MDNS.addServiceTxt("_ddcutil", "_tcp", "1:mfg", mfg.c_str());
}

void setup() {
    Wire.begin();
    wifiSetup();
    if (improvSerial.isConnected()) {
        httpSetup();
        ddcSetup();
    }
}

void loop() {
    wifiLoop();
    if (improvSerial.isConnected()) {
        httpLoop();
    }
}

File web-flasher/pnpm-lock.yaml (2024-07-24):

lockfileVersion: '6.0'

settings:
  autoInstallPeers: true
  excludeLinksFromLockfile: false

dependencies:
  clsx:
    specifier: ^2.1.1
    version: 2.1.1
  framer-motion:
    specifier: ^11.3.17
    version: 11.3.17(react-dom@18.3.1)(react@18.3.1)
  react:
    specifier: ^18.3.1
    version: 18.3.1
  react-dom:
    specifier: ^18.3.1
    version: 18.3.1(react@18.3.1)
  tailwind-merge:
    specifier: ^2.4.0
    version: 2.4.0

devDependencies:
  '@types/react':
    specifier: ^18.3.3
    version: 18.3.3
  '@types/react-dom':
    specifier: ^18.3.0
    version: 18.3.0
  '@vitejs/plugin-basic-ssl':
    specifier: ^1.1.0
    version: 1.1.0(vite@5.3.4)
  '@vitejs/plugin-react-swc':
    specifier: ^3.5.0
    version: 3.7.0(vite@5.3.4)
  autoprefixer:
    specifier: ^10.4.19
    version: 10.4.19(postcss@8.4.39)
  eslint:
    specifier: ^8.57.0
    version: 8.57.0
  eslint-plugin-react:
    specifier: ^7.34.3
    version: 7.35.0(eslint@8.57.0)
  eslint-plugin-react-hooks:
    specifier: ^4.6.2
    version: 4.6.2(eslint@8.57.0)
  eslint-plugin-react-refresh:
    specifier: ^0.4.7
    version: 0.4.9(eslint@8.57.0)
  postcss:
    specifier: ^8.4.39
    version: 8.4.39
  tailwindcss:
    specifier: ^3.4.6
    version: 3.4.6
  vite:
    specifier: ^5.3.4
    version: 5.3.4

packages:

  /@alloc/quick-lru@5.2.0:
    resolution: {integrity: sha512-UrcABB+4bUrFABwbluTIBErXwvbsU/V7TZWfmbgJfbkwiBuziS9gxdODUyuiecfdGQ85jglMW6juS3+z5TsKLw==}
    engines: {node: '>=10'}
    dev: true

  /@esbuild/aix-ppc64@0.21.5:
    resolution: {integrity: sha512-1SDgH6ZSPTlggy1yI6+Dbkiz8xzpHJEVAlF/AM1tHPLsf5STom9rwtjE4hKAF20FfXXNTFqEYXyJNWh1GiZedQ==}
    engines: {node: '>=12'}
    cpu: [ppc64]
    os: [aix]
    requiresBuild: true
    dev: true
    optional: true

  /@esbuild/android-arm64@0.21.5:
    resolution: {integrity: sha512-c0uX9VAUBQ7dTDCjq+wdyGLowMdtR/GoC2U5IYk/7D1H1JYC0qseD7+11iMP2mRLN9RcCMRcjC4YMclCzGwS/A==}
    engines: {node: '>=12'}
    cpu: [arm64]
    os: [android]
    requiresBuild: true
    dev: true
    optional: true

  /@esbuild/android-arm@0.21.5:
    resolution: {integrity: sha512-vCPvzSjpPHEi1siZdlvAlsPxXl7WbOVUBBAowWug4rJHb68Ox8KualB+1ocNvT5fjv6wpkX6o/iEpbDrf68zcg==}
    engines: {node: '>=12'}
    cpu: [arm]
    os: [android]
    requiresBuild: true
    dev: true
    optional: true

  /@esbuild/android-x64@0.21.5:
    resolution: {integrity: sha512-D7aPRUUNHRBwHxzxRvp856rjUHRFW1SdQATKXH2hqA0kAZb1hKmi02OpYRacl0TxIGz/ZmXWlbZgjwWYaCakTA==}
    engines: {node: '>=12'}
    cpu: [x64]
    os: [android]
    requiresBuild: true
    dev: true
    optional: true

  /@esbuild/darwin-arm64@0.21.5:
    resolution: {integrity: sha512-DwqXqZyuk5AiWWf3UfLiRDJ5EDd49zg6O9wclZ7kUMv2WRFr4HKjXp/5t8JZ11QbQfUS6/cRCKGwYhtNAY88kQ==}
    engines: {node: '>=12'}
    cpu: [arm64]
    os: [darwin]
    requiresBuild: true
    dev: true
    optional: true

  /@esbuild/darwin-x64@0.21.5:
    resolution: {integrity: sha512-se/JjF8NlmKVG4kNIuyWMV/22ZaerB+qaSi5MdrXtd6R08kvs2qCN4C09miupktDitvh8jRFflwGFBQcxZRjbw==}
    engines: {node: '>=12'}
    cpu: [x64]
    os: [darwin]
    requiresBuild: true
    dev: true
    optional: true

  /@esbuild/freebsd-arm64@0.21.5:
    resolution: {integrity: sha512-5JcRxxRDUJLX8JXp/wcBCy3pENnCgBR9bN6JsY4OmhfUtIHe3ZW0mawA7+RDAcMLrMIZaf03NlQiX9DGyB8h4g==}
    engines: {node: '>=12'}
    cpu: [arm64]
    os: [freebsd]
    requiresBuild: true
    dev: true
    optional: true

  /@esbuild/freebsd-x64@0.21.5:
    resolution: {integrity: sha512-J95kNBj1zkbMXtHVH29bBriQygMXqoVQOQYA+ISs0/2l3T9/kj42ow2mpqerRBxDJnmkUDCaQT/dfNXWX/ZZCQ==}
    engines: {node: '>=12'}
    cpu: [x64]
    os: [freebsd]
    requiresBuild: true
    dev: true
    optional: true

  /@esbuild/linux-arm64@0.21.5:
    resolution: {integrity: sha512-ibKvmyYzKsBeX8d8I7MH/TMfWDXBF3db4qM6sy+7re0YXya+K1cem3on9XgdT2EQGMu4hQyZhan7TeQ8XkGp4Q==}
    engines: {node: '>=12'}
    cpu: [arm64]
    os: [linux]
    requiresBuild: true
    dev: true
    optional: true

  /@esbuild/linux-arm@0.21.5:
    resolution: {integrity: sha512-bPb5AHZtbeNGjCKVZ9UGqGwo8EUu4cLq68E95A53KlxAPRmUyYv2D6F0uUI65XisGOL1hBP5mTronbgo+0bFcA==}
    engines: {node: '>=12'}
    cpu: [arm]
    os: [linux]
    requiresBuild: true
    dev: true
    optional: true

  /@esbuild/linux-ia32@0.21.5:
    resolution: {integrity: sha512-YvjXDqLRqPDl2dvRODYmmhz4rPeVKYvppfGYKSNGdyZkA01046pLWyRKKI3ax8fbJoK5QbxblURkwK/MWY18Tg==}
    engines: {node: '>=12'}
    cpu: [ia32]
    os: [linux]
    requiresBuild: true
    dev: true
    optional: true

  /@esbuild/linux-loong64@0.21.5:
    resolution: {integrity: sha512-uHf1BmMG8qEvzdrzAqg2SIG/02+4/DHB6a9Kbya0XDvwDEKCoC8ZRWI5JJvNdUjtciBGFQ5PuBlpEOXQj+JQSg==}
    engines: {node: '>=12'}
    cpu: [loong64]
    os: [linux]
    requiresBuild: true
    dev: true
    optional: true
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

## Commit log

2024-07-29 hardware docs
    [HardwareDDC-case-bottom.stl, HardwareDDC-case-top.stl]
2025-04-05 PCBWay Sponsor
2025-04-05 PCBWay logo
2025-08-02 update experiment: HardwareDDC Aux V2.0
    [BOM-hardwareddc-aux-breakout.csv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]
2026-05-17 Update experiment: HardwareDDC Aux V2.1
    [hardwareddc-aux-mitm.kicad_pcb, hardwareddc-aux-mitm.kicad_pcb_bom.csv, hardwareddc-aux-mitm.kicad_pcb_positions.csv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]

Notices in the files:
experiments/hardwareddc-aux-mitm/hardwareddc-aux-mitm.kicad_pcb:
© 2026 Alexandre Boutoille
